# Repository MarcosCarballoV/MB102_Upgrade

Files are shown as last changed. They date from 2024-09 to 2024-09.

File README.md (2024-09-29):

# Custom MB102 PCB Design in Altium Designer


## Overview
This project presents a custom PCB design created in Altium Designer, improving upon the original MB102 power supply module. Key upgrades include LiPo battery support, dynamic power management, USB-C connectivity, and enhanced power control with dual SEPIC switching regulators. Additional features such as configurable SMD buttons, battery monitoring, and independent power source control make this board highly versatile. The design files are ready for manufacturing through JLCPCB or PCBWay.

<p align="center">
  MB102_Upgrade
  <br>
  <em>MB102_Upgrade Render</em>
</p>

## Key Features

- **LiPo Battery Support:** 1-cell LiPo with JST-PH connector.
- **Dynamic Power Path Management:** Optimized LiPo charging and power distribution.
- **USB-C Connector:** Modern interface for power and data.
- **Power Switch:** Full device shutdown capability.
- **Configurable SMD Buttons:** With pull-down/pull-up resistors.
- **Dual SEPIC Switching Regulators:** 5V and 3.3V outputs.
- **3.3V LDO:** For low-power sleep modes.
- **Battery Monitoring:** MOSFET-controlled resistive divider for accurate readings.
- **Battery Status Indicator:** Charging/full status pins.
- **Independent Power Control:** Enable/disable 3.3V or 5V regulators individually.

## Authors

- [@MarcosCarballoV](https://github.com/MarcosCarballoV/)

## Ordering the PCB (JLCPCB/PCBWay)

### JLCPCB
To order this PCB from JLCPCB:
1. **Download Gerber Files:** The necessary Gerber files are included in the `Project Outputs for MB102_Upgrade/MB102_Upgrade_GerberFiles.zip` directory of this repository.
2. **Upload to JLCPCB:**
   - Go to [JLCPCB's website](https://jlcpcb.com/).
   - Click on "Quote Now" and upload the Gerber files.
   - Select your desired options for layer count, color, and PCB thickness.
3. **Order and Checkout:** Complete your order by choosing the shipping method, and submit the payment.

### PCBWay
To order from PCBWay:
1. **Download Gerber Files:** The files are compatible with PCBWay’s system and can be found in the `Project Outputs for MB102_Upgrade/MB102_Upgrade_GerberFiles.zip` folder.
2. **Upload to PCBWay:**
   - Go to [PCBWay's website](https://www.pcbway.com/).
   - Click "Quote Now" and upload the Gerber files.
   - Customize your PCB options like color and surface finish.
3. **Proceed to Checkout:** Finalize your order and select the appropriate shipping option.

## Improvements Over the MB102

This custom PCB offers several key improvements over the MB102:

</p>
<p align="center">
    MB102 Origin
    B102 Improvements
  <br>
  <p align="center">
  <em>Comparison of MB102 Original vs. MB102 Upgrade</em>
</p>

- **Power Supply:** Added support for a 1-cell LiPo battery with a 2-pin JST-PH connector (without NTC).
- **Dynamic Power Path Management:** Integrated LiPo battery charger with dynamic power path management for optimized power distribution. With the [BQ2407x](https://www.ti.com/lit/ds/symlink/bq24074.pdf).
- **USB-C Connector:** Upgraded to a USB-C connector for modern power and data interfaces.
- **Power Control:** Equipped with a switch for complete device shutdown, controlled by a load switch, the [AP2281](https://www.diodes.com/assets/Datasheets/AP2281.pdf).
- **Configurable Buttons:** SMD buttons configurable with pull-down or pull-up resistors.
- **Advanced Power Regulation:** SEPIC-type switching regulators providing stable 5V and 3.3V outputs, using the [TPS63031](https://www.ti.com/lit/ds/symlink/tps63031.pdf), which can achieve 500 mA in step-up and 800 mA in step-down.
- **Low Power Consumption:** Added a 3.3V LDO for projects utilizing microcontroller sleep modes, compatible with any LDO in a SOT23-5 package. In this design, the Enable pin is always active.
- **Battery Monitoring:** Battery level measurement using a resistive divider controlled by MOSFETs for accurate readings.
- **Battery Status Indicator:** Pin and indicator for battery status notifications (charging or fully charged).
- **Independent Power Control:** Pins available to individually enable or disable each switching regulator (3.3V or 5V).

<p align="center">
  Schematic of MB102 Origin page 1
  Schematic of MB102 Origin page 2
  Schematic of MB102 Origin page 3
  <br>
  <em>Schematic of MB102 Upgrade</em>
</p>

## Future Work
We are currently working on ordering the components and assembly for subsequent electrical testing, evaluating the capabilities of the SEPIC sources along with enabling and disabling controls, buttons, and reading voltage and battery status.

## Assembly and Testing

### Physical Assembly
The board was assembled using through-hole and surface-mount components. Special attention was paid to the orientation and placement of key components to ensure that the layout matches the design.

### Electrical Testing
After assembly the boards, the following tests:
- **Continuity Tests:** Ensured that all connections were properly made without any shorts or open circuits.
- **Power-On Test:** Verified the correct voltage outputs (5V and 3.3V) with no significant voltage drops.
- **Load Testing:** The board was tested under different loads to verify that it could maintain stable output voltage without overheating or overloading the components.

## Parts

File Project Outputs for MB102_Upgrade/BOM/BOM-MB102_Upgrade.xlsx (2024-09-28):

# | Quantity | Case/Package | Designator | Manufacturer 1 | Manufacturer Part Number 1 | Description | Supplier 1 | Supplier Part Number 1 | Supplier 2 | Supplier Part Number 2 | Manufacturer 2 | Manufacturer Part Number 2 | Comments
1 | 1 |  | BATT | JST | B2B-PH-K-S(LF)(SN) | JST (JAPAN SOLDERLESS TERMINALS) - B2B-PH-K-S(LF)(SN) - Pin Header, Top Entry, Wire-to-Board, 2 mm, 1 Rows, 2 Contacts, Through Hole, PH Series | LCSC | C131337
2 | 6 | 0603 | C1, C3, C6, C9, C10, C13 | Murata | GRT188R61C475KE13D | 0603 4.7 uF 16 V ±10% Tolerance X5R Multilayer Ceramic Capacitor, MLCC 0603 4.7uF 16V 10% X5R | Mouser | 81-GRT188R61C475KE3D
3 | 1 | 0603 | C2 | Yageo | CC0603KRX5R7BB105 | MLCC 1uF 16V X5R 10% SMD 0603 85C Paper T/R | Mouser | 603-CC603KRX5R7BB105
4 | 2 | 0603 | C4, C5 | Samsung | CL10A106MP8NNND | MLCC 10uF 10V X5R 20% 0603 | Mouser | 187-CL10A106MP8NNND | Mouser | 963-LMK107BBJ106MAHT | Taiyo Yuden | LMK107BBJ106MAHT
5 | 2 | 0603 | C7, C11 | Kyocera AVX | 06035A101JAT2A | AVX - 06035A101JAT2A - SMD Multilayer Ceramic Capacitor, 100 pF, 5%, C0G / NP0, 50 V, 0603 [1608 Metric] RoHS Compliant: Yes | Mouser | 581-06035A101J | Mouser | 77-VJ0603A101JXAAC | Vishay Vitramon | VJ0603A101JXAAC
6 | 2 | 0603 | C8, C12 | Murata | GRM188R61C106MAALD | MLCC 0603 10uF 16V 20% X5R | Mouser | 81-GRM188R61C106MALD | Mouser | 81-ZRB18AR61C106ME1L | Murata | ZRB18AR61C106ME01L
7 | 1 | 0603 | D1 | Wurth Electronics | 150060RS55040 | Red 625nm LED Indication - Discrete 2V 0603 | Mouser | 710-150060RS55040
8 | 1 | 0603 | D4 | Wurth Electronics | 150060VS55040 | Green 575nm LED Indication - Discrete 2V 0603 | Mouser | 710-150060VS55040
9 | 2 | 3015 | L1, L2 | microgate | MPIT3015-1R5N-LF | Inductor Power Shielded Wirewound 1.5uH 20% 152MHz Metal 2.3A 0.05Ohm DCR 1212 T/R | LCSC | C486478
10 | 2 | TO-236 | Q1, Q2 | Nexperia USA | 2N7002,215 | Trans MOSFET N-CH 60V 0.3A 3-Pin TO-236AB T/R | Mouser | 771-2N7002-T/R
11 | 1 | SOT-23-3 | Q3 | Vishay Semiconductors | Si2347DS-T1-GE3 | P-Channel 30 V 42 mOhm 22 nC Surface Mount Power Mosfet - SOT-23-3 | Mouser | 78-SI2347DS-T1-GE3
12 | 8 | 0603 | R1, R6, R7, R13, R14, R16, R17, R19 | Yageo | RC0603FR-07100KL | RES 0603 100K OHM 1% 1/10W | Mouser | 603-RC0603FR-07100KL
13 | 2 | 0603 | R2, R22 | Yageo | RC0603FR-071ML | RES SMD 1M OHM 1% 1/10W 0603, RES 0603 1M OHM 1% 1/10W | Mouser | 603-RC0603FR-071ML
14 | 3 | 0603 | R3, R8, R15 | Yageo | RC0603FR071K2L | RES 0603 1.2K OHM 1% 1/10W | Mouser | 603-RC0603FR-071K2L
15 | 1 | 0603 | R4 | Yageo | RC0603FR-071K5L | RES 0603 1.5K OHM 0.5% 1/10W | Mouser | 603-RC0603FR-071K5L
16 | 2 | 0603 | R5, R21 | Yageo | AF0603FR-0710KL | SMD Chip Resistor, 10 kOhm, ± 1%, 100 mW, 0603 [1608 Metric], Thick Film, Anti-Sulfur | Mouser | 603-AF0603FR-0710KL | Mouser | 667-ERJ-3EKF1002V | Panasonic | ERJ-3EKF1002V
17 | 2 | 0603 | R9, R12 | Yageo | RC0603FR-07220KL | RES 0603 220K OHM 1% 1/10W | Mouser | 603-RC0603FR-07220KL
18 | 2 | 0603 | R10, R11 | Yageo | RC0603FR-075K1L | RES 0603 5.1K OHM 1% 1/10W | Mouser | 603-RC0603FR-075K1L
19 | 2 | 0603 | R18, R20 | TE Connectivity | 1879417-1 | RES 0603 510K OHM 1% 1/10W | Mouser | 279-CPF0603B510KE
20 | 1 | 0603 | R23 | Vishay | CRCW06032M00FKEAC | RES 0603 2M OHM 1% 1/10W | Mouser | 71-CRCW06032M00FKEAC | Digikey | 541-5333-1-ND | Vishay | CRCW06032M00FKEAC
21 | 2 | SMD/SMT | S1, S2 | TE Connectivity | FSMCTA | Switch Tactile OFF (ON) SPST Round Button Gull Wing 0.05A 24VDC 1.57N SMD T/R | Mouser | 506-8-1437565-1
22 | 1 |  | SW1 | TE Connectivity AMP | 1825232-1 | Slide Switch, SPDT, On-on, Latched, 0.2A, 30VDC, Solder Terminal, Panel Mount | Mouser | 655-1825232-1 | Digikey | A107673-ND | TE Connectivity AMP | 1825232-1
23 | 1 | VQFN | U1 | Texas Instruments | BQ24075RGTR | IC LI-ION CHARGE MGMT 16-QFN | Mouser | 595-BQ24075RGTR | Digikey | 296-38874-1-ND | Texas Instruments | BQ24075RGTR
24 | 1 | SOT-23-5 | U2 | Diodes | AP2112K-3.3TRG1 | IC REG LINEAR 3.3V 600MA SOT25 | Mouser | 621-AP2112K-3.3TRG1
25 | 1 | SOT-26 | U3 | Diodes | AP2281-1WG-7 | Load Switch P-Channel 2A SOT-26-6 | Mouser | 621-AP2281-1WG-7 | LCSC | C127279
26 | 2 | WSON-N10 | U4, U5 | Texas Instruments | TPS63030DSKR | Buck-Boost Switching Regulator IC Positive Adjustable 1.2V 1 Output 900mA (Switch) 10-WFDFN Exposed Pad | Mouser | 595-TPS63030DSKR | LCSC | C12462 | Texas Instruments | TPS63030DSKR
27 | 1 | USB C | USB | Global Connector Technology | USB4135-GF-A | Usb C Rec Gf Ra 6P SMT & SMT She | Mouser | 640-USB4135-GF-A

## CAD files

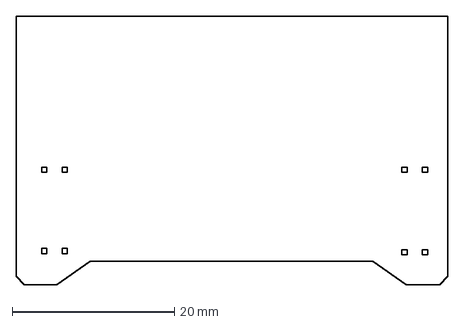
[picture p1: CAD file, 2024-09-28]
MB102.dxf
53.1 x 33.0 mm

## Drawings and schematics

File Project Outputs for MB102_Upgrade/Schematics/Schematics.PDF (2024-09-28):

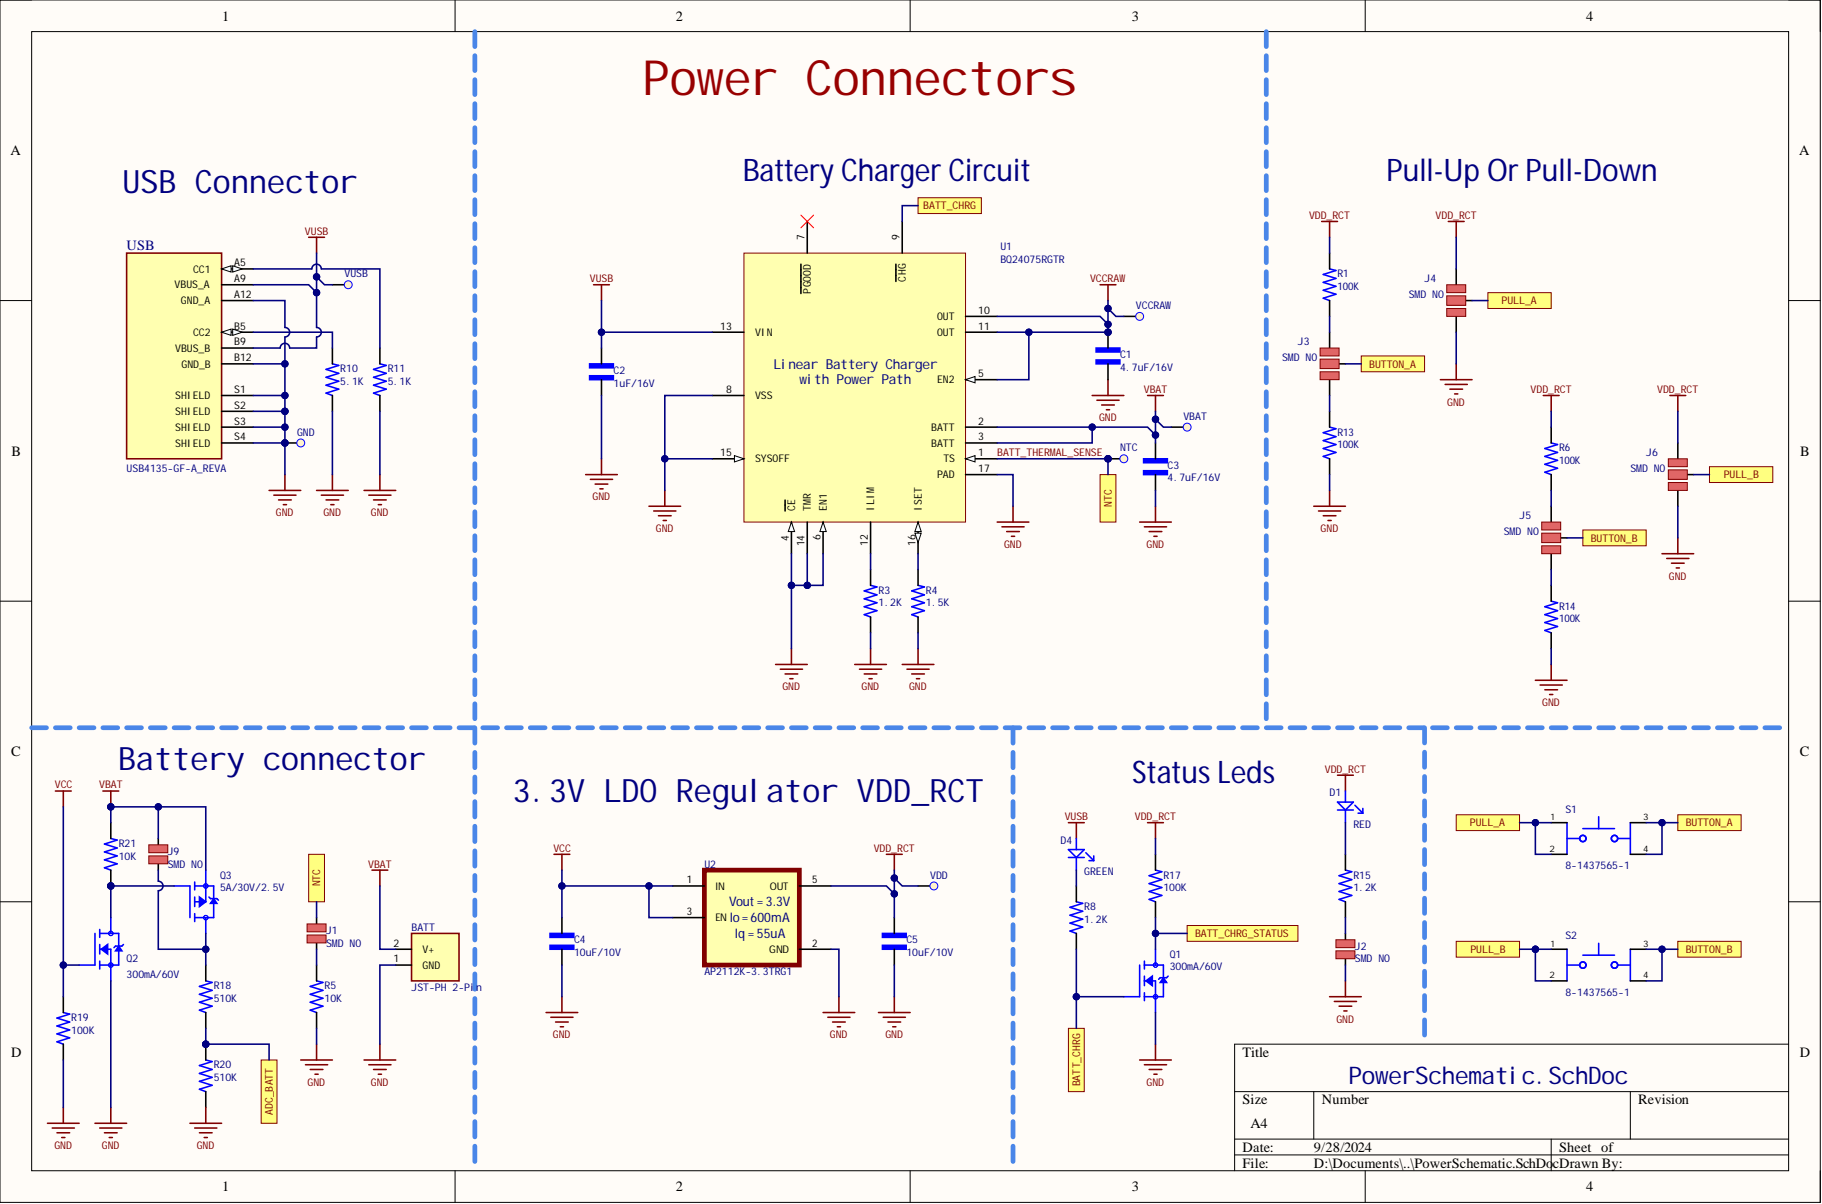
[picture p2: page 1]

Pull-Up Or Pull-Down

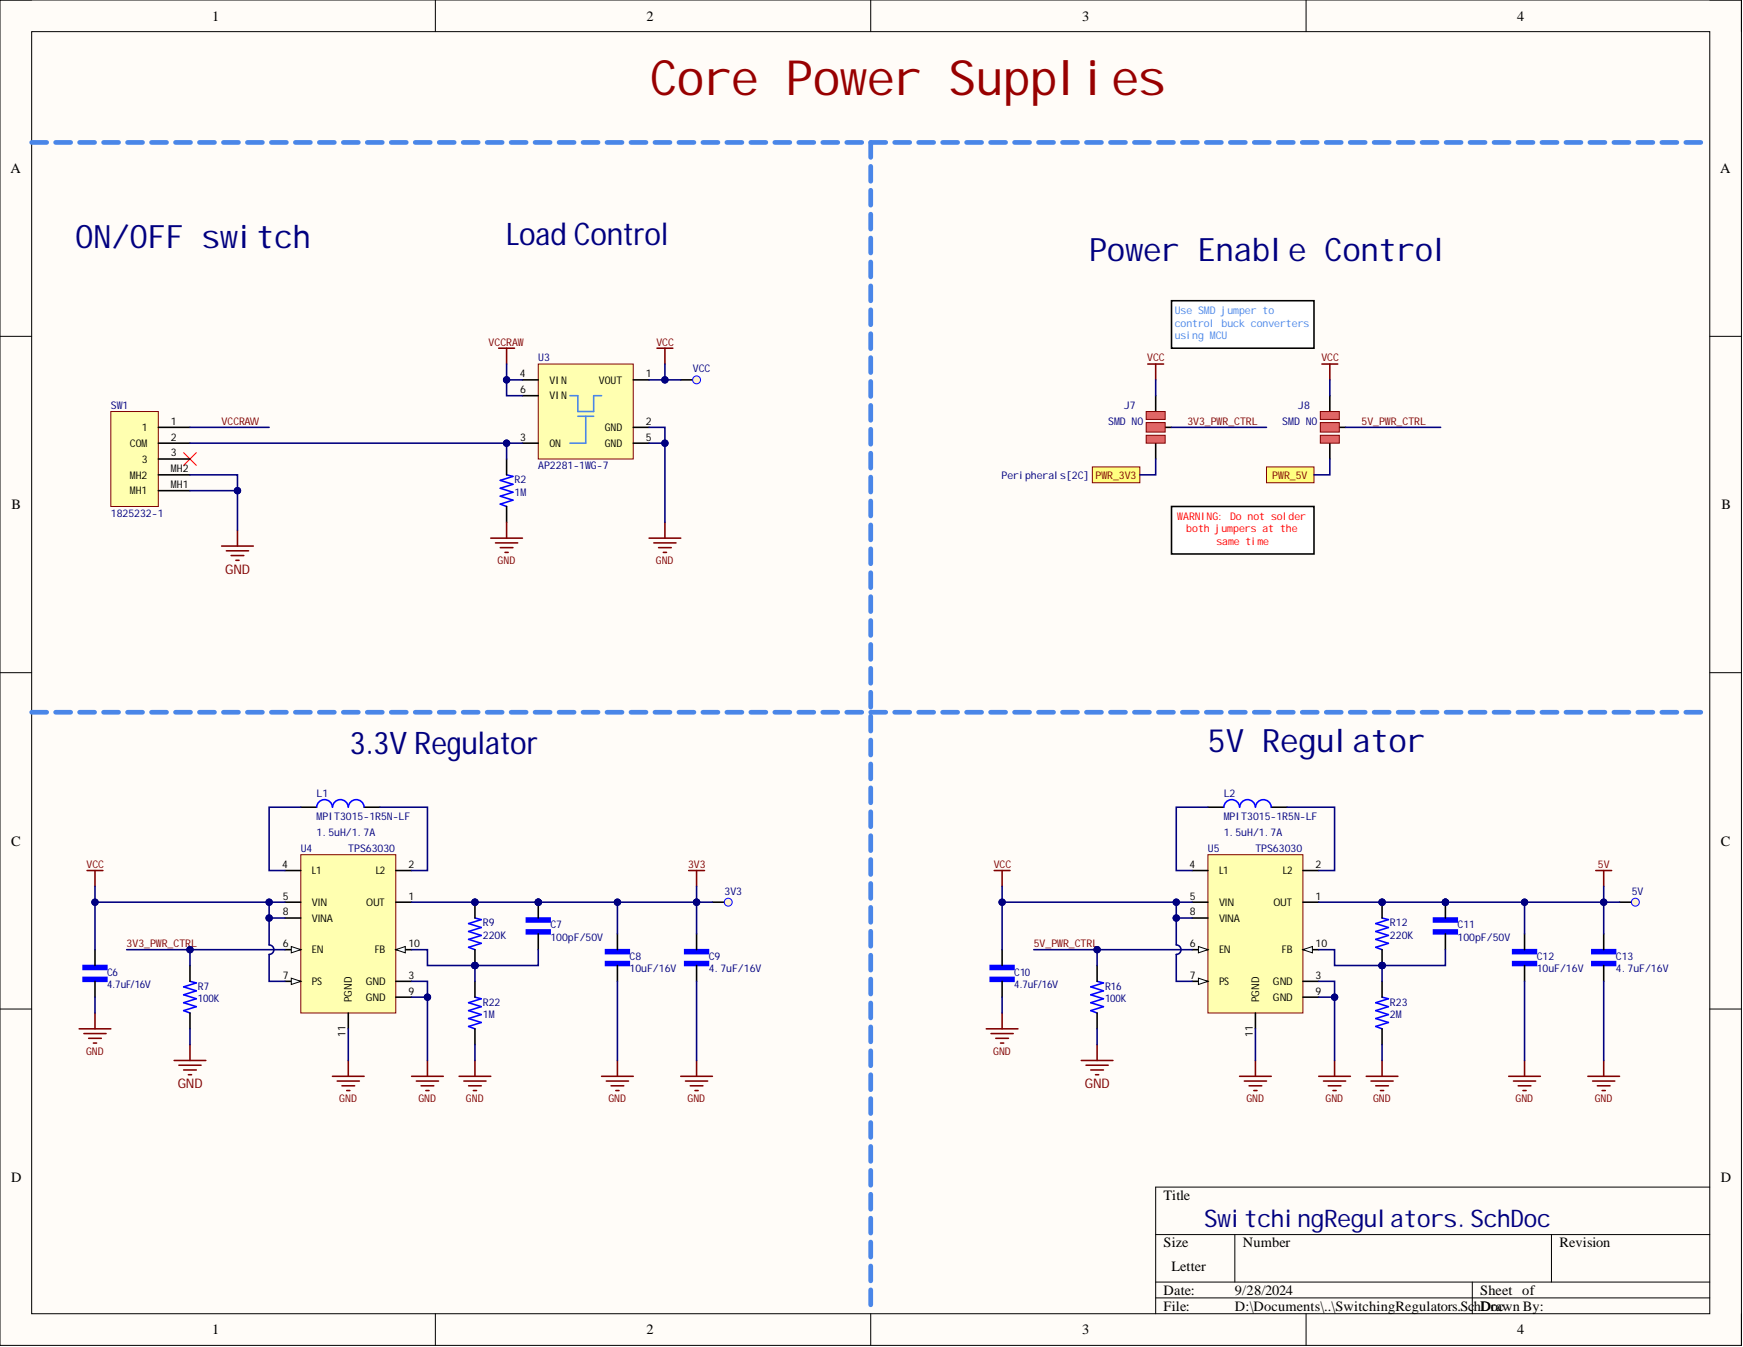
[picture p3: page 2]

Use SMD jumper to
control buck converters
using MCU

WARNING: Do not solder
both jumpers at the
same time

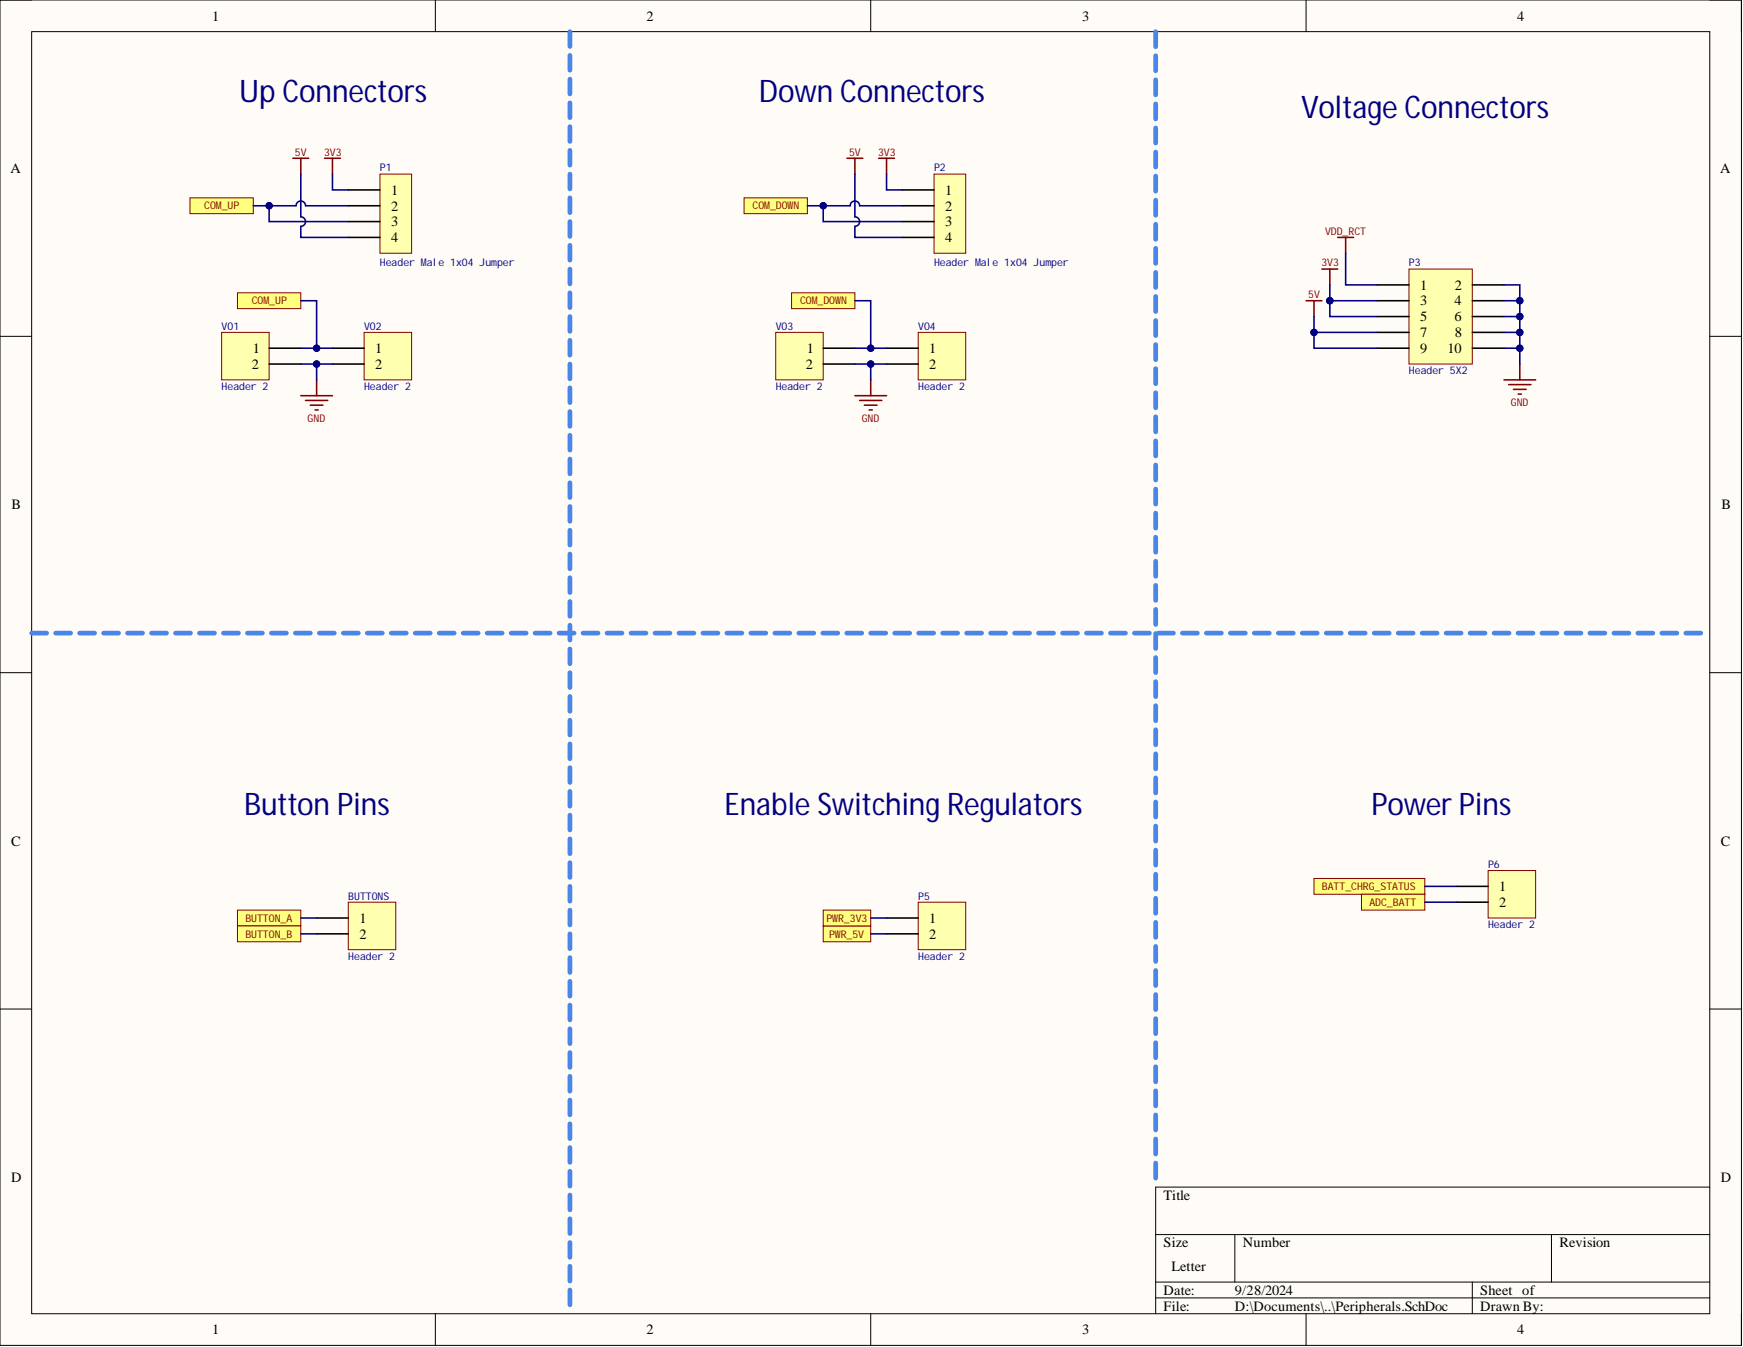
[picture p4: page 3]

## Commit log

2024-09-28 Upload the AD Project
    [BOM-MB102_Upgrade.xlsx, MB102.dxf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]
2024-09-29 Update README.md
    add Schematics
2024-11-23 Fix Bot SilkScreen Jumper
    [MB102_Upgrade.PcbDoc]
2024-12-24 Update Resistors Feedback
    [SwitchingRegulators.SchDoc]
